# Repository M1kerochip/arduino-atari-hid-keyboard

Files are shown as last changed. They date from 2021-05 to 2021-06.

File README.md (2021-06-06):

Interface Atari ST Keyboard to USB HID Keyboard
===============================================

This code runs on an ATmega32U4 based Arduino to provide an interface between an Atari ST keyboard (8 Pin, 18 Pin and RJ11) and a USB HID keyboard device.
Atari 520 STFM (UK), Atari 1040 STE (UK) and Atari TT keyboards tested.

The purpose of this is to allow an ST keyboard to be used with any machine that accepts USB HID Keyboards.

Developed for use with an ATmega32U4 based Arduino (eg Micro, Leonardo, Pro Micro etc) as it is able to act directly as a USB keyboard controller.

### The Atari keyboard connector is wired to the Arduino as follows:

| Atari 8-pin Keyboard Connector  | Arduino |
| --- |:---:|
| Pin 1: 0V | GND |
| Pin 2: Blocked (Unused) | - |
| Pin 3: (Unused) | - |
| Pin 4: 5V | 5V |
| Pin 5: TX | RX (PD2) |
| Pin 6: RX | TX (PD3) |
| Pin 7: Reset | Digital Pin 8 (PB6) |
| Pin 8: Floppy Drive Light |  Digital Pin 9 (PF7) |

To use an 18 pin original ST connector, just connect pins 1-8, using the blocked/missing pin as pin 2.
The other pins are unused for keyboard purposes. (They contain the 9pin mouse/keyboard inputs from the main PCB)

### To use an RJ11 based keyboard (Mega ST, Mega STE, TT)

| Atari RJ11 Keyboard Connector  | Arduino |
| --- |:---:|
| Pin 1: 5V | 5V |
| Pin 2: 5V | 5V |
| Pin 3: RX | TX (PD3) |
| Pin 4: TX | RX (PD2) |
| Pin 5: 0V | GND |
| Pin 6: 0V | GND |

<br>
Initial idea and some original code provided by user 'joska' of http://www.atari-forum.com - license unknown <br><br>
Copyright Kevin Peat 2017 kevin 'at' kevinpeat.com <br>
My changes and additions are licensed public domain <br><br>
See http://www.kevinpeat.com/atari_pi_reworked.html for my hybrid Atari ST Raspberry Pi project.<br><br>

Additional code by Michael Farrell 2021

### 2021-05-18 (MF)

* Switched over development from the Arduino IDE to PlatformIO using Visual Studio Code.
* Program/sketch is now main.cpp instead of USB_HID_Keyboard.ino
* The Arduino keyboard.h treats values below 128 as printable and uses an ascii lookup table. It add 136 to the value to overcome this. Therefore keycodes above 120 cannot be used.
* The ( and ) numperpad keys are keycodes 182 and 183.
* Fixed the incorrect keycodes for all the numberpad keys except the two above.
* Changed Numberpad Enter key to scancode 88: Keypad Enter
* Changed the \ | key to scancode 49: Keyboard \ and |
* Changed the #~ key to scancode 50: Keyboard Non-US # and ~
* Changed Help to F11 and Undo to F12.
* Keycode list: from https://www.usb.org/sites/default/files/documents/hut1_12v2.pdf
* Tidied up README.md.
* Added information on how to connect external keyboards.

### 2021-05-27 (MF)

* Removed and rewrote the previous code, to better understand it.
* Added initial Joystick 0 code.

### 2021-06-06 (MF)

* Fixed Joystick 0 code.
* Added German Atari ST keyboard layout.

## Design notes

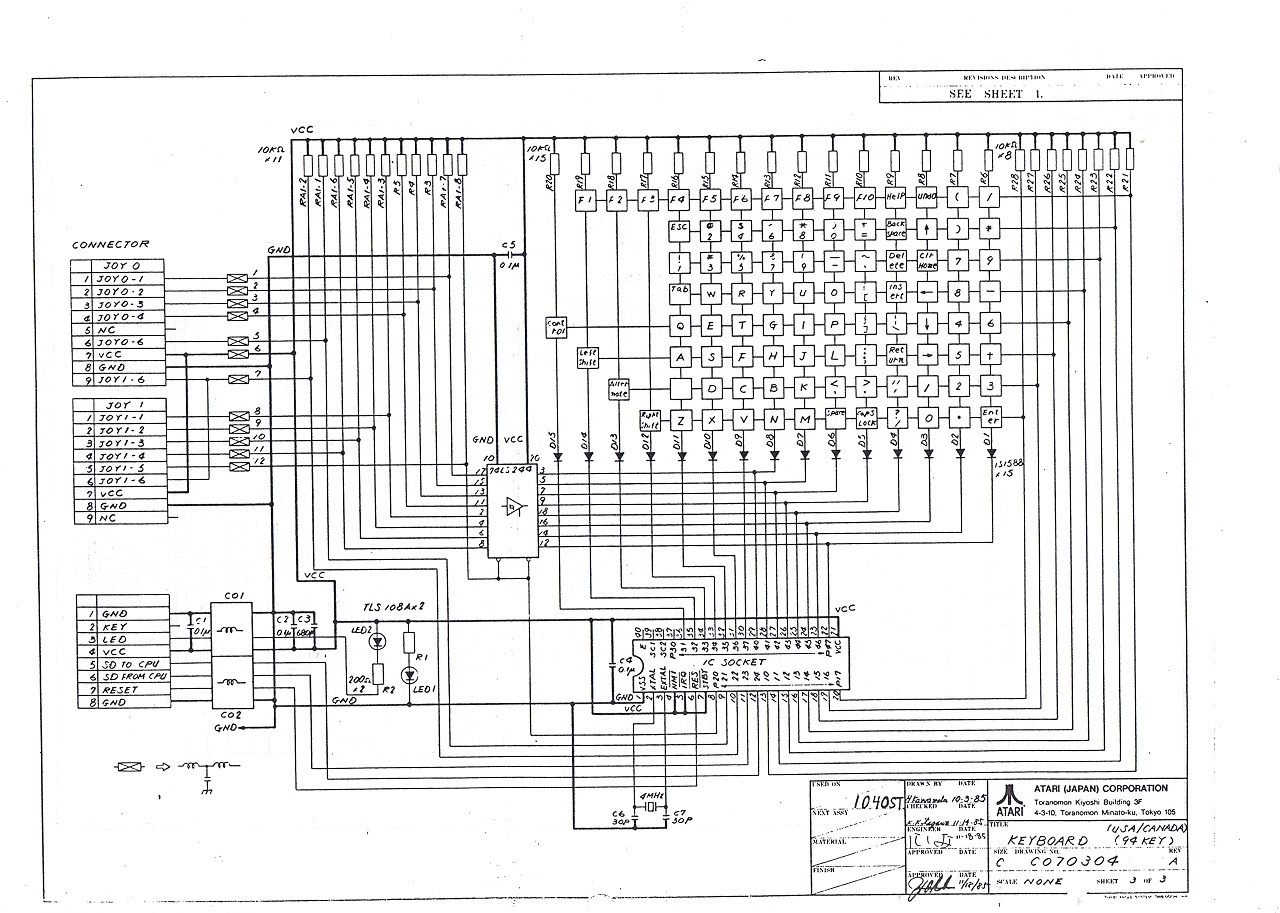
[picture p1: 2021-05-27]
Pics/3343072926_2483ae8421_o.jpg

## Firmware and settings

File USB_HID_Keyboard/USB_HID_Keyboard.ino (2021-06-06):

#include <Arduino.h>
/* 
* -------------------------------------------------------------------------
* Interface Atari ST Keyboard to USB HID Keyboard
* -------------------------------------------------------------------------
* Initial idea and some original code provided by user 'joska' of 
* http://www.atari-forum.com - license unknown
* Based on Arduino code from Kevin Peat 2017  -  kevin@kevinpeat.com
* -------------------------------------------------------------------------
* Copyright Michael Farrell 2021
* mikerochip(at)hotmail.com
*
* -------------------------------------------------------------------------
* Arduino USB HID interface for ATmega32U4 based controllers:
* Leonardo, Micro, Pro Micro, etc.
* Supports 6 pin RJ11, 7 pin and 18 pin Atari Keyboards from:
* Atari ST, STF, STM, STFM, STE, Mega ST, Mega STE, TT, Falcon
* Includes UK and US keyboard layout.
* Optionally supports:
* Joystick Player 1. (Should be plugged in before connecting keyboard)
* Digital Pin 8 can be used to reset the 7 / 18 pin keyboards.
* Digital Pin 9 can be connected to use the floppy drive led as a capslock led.
* TODO: Figure out mouse / Joystick Player 2
* -------------------------------------------------------------------------
*/

// Define to include console output.
// #define DEBUG

// Define this, to use the normal Arduino Keyboard library.
#define ArduinoKeyboard_Source

#ifdef ArduinoKeyboard_Source
#include <Keyboard.h>
#else
#include <Keyboard_Real.h>
#endif

// Define this, to enable Joysticks and Mouse support, with the ST Keyboard
// #define JoystickMouse_Support

#ifdef JoystickMouse_Support
#include "Joystick.h" // For Joystick control (mheironimus/Joystick)
#include "Mouse.h"    // For Arduino Mouse
#endif

// define, to use the UK keyboard layout.
#define UK_ATARI_KEYBOARD

// define, to use the US Keyboard layout.
// #define US_ATARI_KEYBOARD

// define, to use the German keyboard layout.
// #define DE_ATARI_KEYBOARD

/*
For 7 pin Atari keyboards, you can use the floppy LED as a caps lock LED
Unsupported on RJ11 external Keyboards: Mega ST, Mega STE, TT
*/
// #define UseFloppyCapsLock // Define, to use the floppy LED as capslock LED

#ifdef UseFloppyCapsLock
// ST keyboard Floppy LED pin
const int ST_FLOPPY_LED = 9; // D9 for Arduino (Pro) Micro
#endif

#ifdef JoystickMouse_Support
#define MAXBUTTONS 1     // The number of buttons you are using up to 9, for 2 player mode.
#define JOYSTICK_COUNT 2 // The number of joysticks connected to the Arduino

//Create Joystick objects
#if JOYSTICK_COUNT == 1
Joystick_ Joystick[JOYSTICK_COUNT] =
    {
        Joystick_(0x03, JOYSTICK_TYPE_GAMEPAD, MAXBUTTONS, 0, true, true, false, false, false, false, false, false, false, false, false)};
#endif

#if JOYSTICK_COUNT == 2
Joystick_ Joystick[JOYSTICK_COUNT] =
    {
        Joystick_(0x03, JOYSTICK_TYPE_GAMEPAD, MAXBUTTONS, 0, true, true, false, false, false, false, false, false, false, false, false),
        Joystick_(0x04, JOYSTICK_TYPE_GAMEPAD, MAXBUTTONS, 0, true, true, false, false, false, false, false, false, false, false, false),
};
#endif
/* Use ID 03 for first joystick, 04 for second joystick
   Joystick type: gamepad / digital joystick
   MAXBUTTONS: Button Count (Both sticks will be the same)
   0:  Hat Switch Count
   X Axis. We need at least two axes. 
   Y Axis. Second axis used.
   No Z Axis  
   No Rx
   No Ry
   No Rz
   No rudder
   No throttle      
   No accelerator
   No brake
   No steering
*/

const int16_t Joy0 = 0xFF;             // Initial Serial char for Joystick 0 Commands
const int16_t Joy1 = 0xF2;             // Initial Serial char for Joystick 1 Commands
const uint8_t JoyBtnReleaseAll = 0xF8; // Initial Serial char for Release Both Joystick/Mouse Fire buttons
const uint8_t JoyBtnPress0 = 0xF9;     // Initial Serial char for Press Joystick 0 Fire
const uint8_t JoyBtnPress1 = 0xFA;     // Initial Serial char for Press Joystick 1 Fire
const uint8_t JoyBtnPressBoth = 0xFB;  // Initial Serial char for Press Joystick 0+1 Fire together
#endif

// ST keyboard reset pin
const int ST_KB_RESET = 8; // D8 for Arduino (Pro) Micro

const uint8_t FirstKeypress = 0x01;
const uint8_t LastKeypress = 0x72;

uint8_t No_Op_Count = 0x00; //Loop, to not process the next serial bytes, since they're part of the previous instruction
uint8_t Prev_Serial_Byte = 0x00;
int16_t ActionByte = 0x00;

// Atari modifier key codes
const uint8_t ST_LEFT_CTRL = 0x1D;
const uint8_t ST_LEFT_SHIFT = 0x2A;
const uint8_t ST_LEFT_ALT = 0x38;
const uint8_t ST_RIGHT_SHIFT = 0x36;
const uint8_t ST_CAPS_LOCK = 0x3A;

/*
  The Arduino Keyboard.h subtracts 136 from all keyboard codes above 136.
  To get the real code, add 136 to it.
  It also subtracts 128 from all keycodes from 128-135.
  If using a proper keyboard library, set to 0
*/
#ifdef ArduinoKeyboard_Source
const int KeyboardStupid = 0x88;
#else
const int KeyboardStupid = 0x00;
#endif

const uint8_t Key_BackSlashPipe = 0x31 + KeyboardStupid;
const uint8_t Key_TildeHash_NonUS = 0x32 + KeyboardStupid;
const uint8_t Key_GraveAccentTilde = 0x35 + KeyboardStupid;
const uint8_t NUM_Slash = 0x54 + KeyboardStupid;
const uint8_t NUM_Star = 0x55 + KeyboardStupid;
const uint8_t NUM_Minus = 0x56 + KeyboardStupid;
const uint8_t NUM_Plus = 0x57 + KeyboardStupid;
const uint8_t NUM_Enter = 0x58 + KeyboardStupid;
const uint8_t NUM_1 = 0x59 + KeyboardStupid;
const uint8_t NUM_2 = 0x5A + KeyboardStupid;
const uint8_t NUM_3 = 0x5B + KeyboardStupid;
const uint8_t NUM_4 = 0x5C + KeyboardStupid;
const uint8_t NUM_5 = 0x5D + KeyboardStupid;
const uint8_t NUM_6 = 0x5E + KeyboardStupid;
const uint8_t NUM_7 = 0x5F + KeyboardStupid;
const uint8_t NUM_8 = 0x60 + KeyboardStupid;
const uint8_t NUM_9 = 0x61 + KeyboardStupid;
const uint8_t NUM_0 = 0x62 + KeyboardStupid;
const uint8_t NUM_Period = 0x63 + KeyboardStupid;
const uint8_t Key_BackSlashPipe_NonUS = 0x64 + KeyboardStupid;

/* 
  Arduino treats values below 128 as printable and uses an ascii lookup table. 
  Add 136 to the value to overcome this.
  Because of this, keycodes above 120 cannot be used.
  https://forum.arduino.cc/index.php?topic=179548.0
  https://www.usb.org/sites/default/files/documents/hut1_12v2.pdf
*/

#ifdef US_ATARI_KEYBOARD
// US ST Layout, for US USB HID Keyboard
uint8_t scanCodes[] =
    {
        0x00,                 // (Nothing)
        KEY_ESC,              // Esc
        0x31,                 // 1
        0x32,                 // 2
        0x33,                 // 3
        0x34,                 // 4
        0x35,                 // 5
        0x36,                 // 6
        0x37,                 // 7
        0x38,                 // 8
        0x39,                 // 9
        0x30,                 // 0
        0x2D,                 // -
        0x3D,                 // == (Mapped to =)
        KEY_BACKSPACE,        // Backspace
        KEY_TAB,              // Tab
        0x71,                 // q
        0x77,                 // w
        0x65,                 // e
        0x72,                 // r
        0x74,                 // t
        0x79,                 // y
        0x75,                 // u
        0x69,                 // i
        0x6F,                 // o
        0x70,                 // p
        0x5B,                 // [
        0x5D,                 // ]
        KEY_RETURN,           // Enter
        KEY_LEFT_CTRL,        // Control
        0x61,                 // a
        0x73,                 // s
        0x64,                 // d
        0x66,                 // f
        0x67,                 // g
        0x68,                 // h
        0x6A,                 // j
        0x6B,                 // k
        0x6C,                 // l
        0x3B,                 // ;
        0x27,                 // ' (Mapped to '")
        Key_GraveAccentTilde, // ` and ~
        KEY_LEFT_SHIFT,       // Lshift
        Key_BackSlashPipe,    // \ and |
        0x7A,                 // z
        0x78,                 // x
        0x63,                 // c
        0x76,                 // v
        0x62,                 // b
        0x6E,                 // n
        0x6D,                 // m
        0x2C,                 // ,
        0x2E,                 // .
        0x2F,                 // /
        KEY_RIGHT_SHIFT,      // Rshift
        0x37,                 // (Not used)
        KEY_LEFT_ALT,         // Alternate
        0x20,                 // Space
        KEY_CAPS_LOCK,        // CapsLock
        KEY_F1,               // F1
        KEY_F2,               // F2
        KEY_F3,               // F3
        KEY_F4,               // F4
        KEY_F5,               // F5
        KEY_F6,               // F6
        KEY_F7,               // F7
        KEY_F8,               // F8
        KEY_F9,               // F9
        KEY_F10,              // F10
        0x45,                 // (Not used)
        0x46,                 // (Not used)
        KEY_HOME,             // Clr/Home
        KEY_UP_ARROW,         // Up Arrow
        0x49,                 // (Not used)
        NUM_Minus,            // Numeric Pad -
        KEY_LEFT_ARROW,       // Left Arrow
        0x4c,                 // (Not used)
        KEY_RIGHT_ARROW,      // Right Arrow
        NUM_Plus,             // Numeric Pad +
        0x4f,                 // (Not used)
        KEY_DOWN_ARROW,       // Down Arrow
        0x51,                 // (Not used)
        KEY_INSERT,           // Insert
        KEY_DELETE,           // Delete
        0x54,                 // (Not used)
        0x55,                 // (Not used)
        0x56,                 // (Not used)
        0x57,                 // (Not used)
        0x58,                 // (Not used)
        0x59,                 // (Not used)
        0x5a,                 // (Not used)
        0x5b,                 // (Not used)
        0x5c,                 // (Not used)
        0x5d,                 // (Not used)
        0x5e,                 // (Not used)
        0x5f,                 // (Not used)
        0x5C,                 // ISO Key
        KEY_F12,              // Undo (Mapped to F12)
        KEY_F11,              // Help (Mapped to F11)
        0x28,                 // Numeric Pad ( [Mapped to ( since the Arduino keyboard can't map keycode 182]
        0x29,                 // Numeric Pad ) [Mapped to ) since the Arduino keyboard can't map keycode 183]
        NUM_Slash,            // Numeric Pad /
        NUM_Star,             // Numeric Pad *
        NUM_7,                // Numeric Pad 7
        NUM_8,                // Numeric Pad 8
        NUM_9,                // Numeric Pad 9
        NUM_4,                // Numeric Pad 4
        NUM_5,                // Numeric Pad 5
        NUM_6,                // Numeric Pad 6
        NUM_1,                // Numeric Pad 1
        NUM_2,                // Numeric Pad 2
        NUM_3,                // Numeric Pad 3
        NUM_0,                // Numeric Pad 0
        NUM_Period,           // Numeric Pad .
        NUM_Enter             // Numeric Pad Enter
};
#endif

#ifdef UK_ATARI_KEYBOARD
// UK ST Layout, for UK British USB HID Keyboard
uint8_t scanCodes[] =
    {
        0x00,                    // (Nothing)
        KEY_ESC,                 // Esc
        0x31,                    // 1
        0x32,                    // 2
        0x33,                    // 3
        0x34,                    // 4
        0x35,                    // 5
        0x36,                    // 6
        0x37,                    // 7
        0x38,                    // 8
        0x39,                    // 9
        0x30,                    // 0
        0x2D,                    // -
        0x3D,                    // == (Mapped to =)
        KEY_BACKSPACE,           // Backspace
        KEY_TAB,                 // Tab
        0x71,                    // q
        0x77,                    // w
        0x65,                    // e
        0x72,                    // r
        0x74,                    // t
        0x79,                    // y
        0x75,                    // u
        0x69,                    // i
        0x6F,                    // o
        0x70,                    // p
        0x5B,                    // [
        0x5D,                    // ]
        KEY_RETURN,              // Enter
        KEY_LEFT_CTRL,           // Control
        0x61,                    // a
        0x73,                    // s
        0x64,                    // d
        0x66,                    // f
        0x67,                    // g
        0x68,                    // h
        0x6A,                    // j
        0x6B,                    // k
        0x6C,                    // l
        0x3B,                    // ;
        0x27,                    // ' (Mapped to '")
        Key_GraveAccentTilde,    // #
        KEY_LEFT_SHIFT,          // Lshift
        Key_TildeHash_NonUS,     // #~
        0x7A,                    // z
        0x78,                    // x
        0x63,                    // c
        0x76,                    // v
        0x62,                    // b
        0x6E,                    // n
        0x6D,                    // m
        0x2C,                    // ,
        0x2E,                    // .
        0x2F,                    // /
        KEY_RIGHT_SHIFT,         // Rshift
        0x37,                    // (Not used)
        KEY_LEFT_ALT,            // Alternate
        0x20,                    // Space
        KEY_CAPS_LOCK,           // CapsLock
        KEY_F1,                  // F1
        KEY_F2,                  // F2
        KEY_F3,                  // F3
        KEY_F4,                  // F4
        KEY_F5,                  // F5
        KEY_F6,                  // F6
        KEY_F7,                  // F7
        KEY_F8,                  // F8
        KEY_F9,                  // F9
        KEY_F10,                 // F10
        0x45,                    // (Not used)
        0x46,                    // (Not used)
        KEY_HOME,                // Clr/Home
        KEY_UP_ARROW,            // Up Arrow
        0x49,                    // (Not used)
        NUM_Minus,               // Numeric Pad -
        KEY_LEFT_ARROW,          // Left Arrow
        0x4c,                    // (Not used)
        KEY_RIGHT_ARROW,         // Right Arrow
        NUM_Plus,                // Numeric Pad +
        0x4f,                    // (Not used)
        KEY_DOWN_ARROW,          // Down Arrow
        0x51,                    // (Not used)
        KEY_INSERT,              // Insert
        KEY_DELETE,              // Delete
        0x54,                    // (Not used)
        0x55,                    // (Not used)
        0x56,                    // (Not used)
        0x57,                    // (Not used)
        0x58,                    // (Not used)
        0x59,                    // (Not used)
        0x5a,                    // (Not used)
        0x5b,                    // (Not used)
        0x5c,                    // (Not used)
        0x5d,                    // (Not used)
        0x5e,                    // (Not used)
        0x5f,                    // (Not used)
        Key_BackSlashPipe_NonUS, // Keyboard Non-US \ and |
        KEY_F12,                 // Undo (Mapped to F12)
        KEY_F11,                 // Help (Mapped to F11)
        0x28,                    // Numeric Pad ( [Mapped to ( since the Arduino keyboard can't map keycode 182]
        0x29,                    // Numeric Pad ) [Mapped to ) since the Arduino keyboard can't map keycode 183]
        NUM_Slash,               // Numeric Pad /
        NUM_Star,                // Numeric Pad *
        NUM_7,                   // Numeric Pad 7
        NUM_8,                   // Numeric Pad 8
        NUM_9,                   // Numeric Pad 9
        NUM_4,                   // Numeric Pad 4
        NUM_5,                   // Numeric Pad 5
        NUM_6,                   // Numeric Pad 6
        NUM_1,                   // Numeric Pad 1
        NUM_2,                   // Numeric Pad 2
        NUM_3,                   // Numeric Pad 3
        NUM_0,                   // Numeric Pad 0
        NUM_Period,              // Numeric Pad .
        NUM_Enter                // Numeric Pad Enter
};
#endif

#ifdef DE_ATARI_KEYBOARD
// German ST Layout, for DE USB HID Keyboard
uint8_t scanCodes[] =
    {
        0x00,                    // (Nothing)
        KEY_ESC,                 // Esc
        0x31,                    // 1
        0x32,                    // 2
        0x33,                    // 3
        0x34,                    // 4
        0x35,                    // 5
        0x36,                    // 6
        0x37,                    // 7
        0x38,                    // 8
        0x39,                    // 9
        0x30,                    // 0=
        0x2D,                    // ß?
        0x3D,                    // ´´
        KEY_BACKSPACE,           // Backspace
        KEY_TAB,                 // Tab
        0x71,                    // q
        0x77,                    // w
        0x65,                    // e
        0x72,                    // r
        0x74,                    // t
        0x79,                    // y or z
        0x75,                    // u
        0x69,                    // i
        0x6F,                    // o
        0x70,                    // p
        0x3B,                    // Ö
        0x27,                    // Ä
        KEY_RETURN,              // Enter
        KEY_LEFT_CTRL,           // Control
        0x61,                    // a
        0x73,                    // s
        0x64,                    // d
        0x66,                    // f
        0x67,                    // g
        0x68,                    // h
        0x6A,                    // j
        0x6B,                    // k
        0x6C,                    // l
        0x2C,                    // ,;
        0x5B,                    // ü
        Key_GraveAccentTilde,    // ^^
        KEY_LEFT_SHIFT,          // Lshift
        Key_BackSlashPipe,       // <-- Incorrect TODO: Fix!
        0x7A,                    // z
        0x78,                    // x
        0x63,                    // c
        0x76,                    // v
        0x62,                    // b
        0x6E,                    // n
        0x6D,                    // m
        Key_BackSlashPipe_NonUS, // <>
        0x2E,                    // .:
        0x2F,                    // -_
        KEY_RIGHT_SHIFT,         // Rshift
        0x37,                    // (Not used)
        KEY_LEFT_ALT,            // Alternate
        0x20,                    // Space
        KEY_CAPS_LOCK,           // CapsLock
        KEY_F1,                  // F1
        KEY_F2,                  // F2
        KEY_F3,                  // F3
        KEY_F4,                  // F4
        KEY_F5,                  // F5
        KEY_F6,                  // F6
        KEY_F7,                  // F7
        KEY_F8,                  // F8
        KEY_F9,                  // F9
        KEY_F10,                 // F10
        0x45,                    // (Not used)
        0x46,                    // (Not used)
        KEY_HOME,                // Clr/Home
        KEY_UP_ARROW,            // Up Arrow
        0x49,                    // (Not used)
        NUM_Minus,               // Numeric Pad -
        KEY_LEFT_ARROW,          // Left Arrow
        0x4c,                    // (Not used)
        KEY_RIGHT_ARROW,         // Right Arrow
        NUM_Plus,                // Numeric Pad +
        0x4f,                    // (Not used)
        KEY_DOWN_ARROW,          // Down Arrow
        0x51,                    // (Not used)
        KEY_INSERT,              // Insert
        KEY_DELETE,              // Delete
        0x54,                    // (Not used)
        0x55,                    // (Not used)
        0x56,                    // (Not used)
        0x57,                    // (Not used)
        0x58,                    // (Not used)
        0x59,                    // (Not used)
        0x5a,                    // (Not used)
        0x5b,                    // (Not used)
        0x5c,                    // (Not used)
        0x5d,                    // (Not used)
        0x5e,                    // (Not used)
        0x5f,                    // (Not used)
                                 //        Key_BackSlashPipe_NonUS, // Keyboard Non-US \ and |
        0x5D,                    //
        KEY_F12,                 // Undo (Mapped to F12)
        KEY_F11,                 // Help (Mapped to F11)
        0x28,                    // Numeric Pad ( [Mapped to ( since the Arduino keyboard can't map keycode 182]
        0x29,                    // Numeric Pad ) [Mapped to ) since the Arduino keyboard can't map keycode 183]
        NUM_Slash,               // Numeric Pad /
        NUM_Star,                // Numeric Pad *
        NUM_7,                   // Numeric Pad 7
        NUM_8,                   // Numeric Pad 8
        NUM_9,                   // Numeric Pad 9
        NUM_4,                   // Numeric Pad 4
        NUM_5,                   // Numeric Pad 5
        NUM_6,                   // Numeric Pad 6
        NUM_1,                   // Numeric Pad 1
        NUM_2,                   // Numeric Pad 2
        NUM_3,                   // Numeric Pad 3
        NUM_0,                   // Numeric Pad 0
        NUM_Period,              // Numeric Pad .
        NUM_Enter                // Numeric Pad Enter
};
#endif

#ifdef UseFloppyCapsLock
boolean CapsState = true;
/*
Switch on/off the floppy drive led via the ST_FLOPPY_LED Pin.
*/
void TurnOnOfFloppyLED(int HighLow)
{
  pinMode(ST_FLOPPY_LED, OUTPUT);
  digitalWrite(ST_FLOPPY_LED, HighLow); // For output, HIGH is 5v, LOW is 0v
}
#endif
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
void loop()
{
  if (Serial1.available() > 0)
  {
    Handle_Serial(Serial1.read());
  }
}

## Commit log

2021-05-19 Changes to fix numeric keypad etc. Switch to PlatformIO.
    [main.cpp]
2021-05-27 joy0 support (preliminary)
    [Arduino Leonardo Shield - Atari ST Keyboard 8Pin-18Pin-RJ11-Shield.REV0.fzz, Atari ST(E)_MegaST_MegaSTE_TT_Falcon_Keyboard-To-Arduino_Micro_REV0.fzz, Atari ST(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]
2021-06-06 corrected capslock / floppy led
    [Atari ST(E)_MegaST_MegaSTE_TT_Falcon_Keyboard-To-Arduino_Micro_REV6.fzz]
2021-06-25 update PCB
    [Arduino Leonardo Shield - Atari ST Keyboard 8Pin-18Pin-RJ11-Shield.REV1.fzz, Atari ST(E)_MegaST_MegaSTE_TT_Falcon_Keyboard-To-Arduino_Micro_REV7.fzz]
